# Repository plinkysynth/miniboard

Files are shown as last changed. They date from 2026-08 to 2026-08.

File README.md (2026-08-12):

# miniboard - a super minimal fatar tp9 37 key keybed scanner using an rp2040 mcu by @mmalex.bsky.social

August 2026

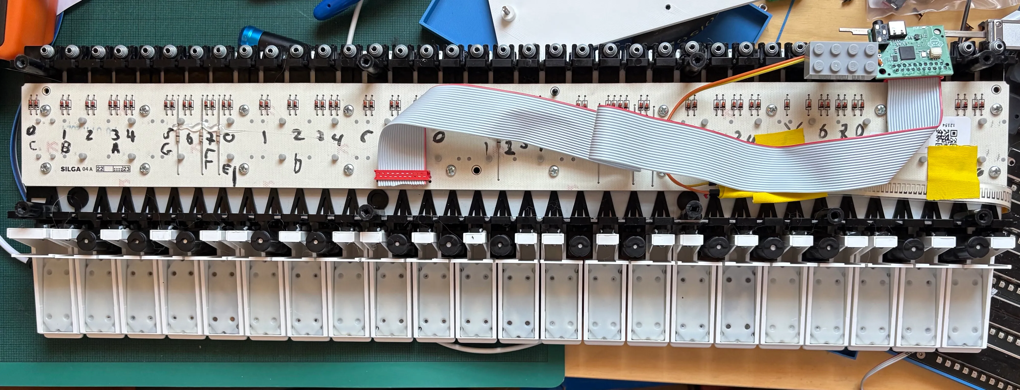
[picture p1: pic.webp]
miniboard


## the keybed wot you need

there's no point looking at this project until you are the proud owner of a fatar 9s keybed. probably the 37 key variant. 

- the keybed - https://www.fatar.com/products/tp9s/
- datasheet - https://www.antonus-synths.com/enlo-1/fatar/DataSheet-TP9S%2BP.pdf

I got mine at great expense a few years ago from
https://enlo-1.com/products/fatar-tp-9s-keyboard
but im not sure if they are meant to sell them to us hobbyists? either way it was expensive for what it is! maybe you can find one cheaper somewhere else. I am not affiliated with them in any way, just documenting my build.

## whence came this mess

forked from my earlier 2024 zacboard project, that included an oled, 2 encoders, and a silly set of i2c slider boards that allowed it to sport more sliders than keys.

im not sure if i ever released that one publically (* i did not), but i was curious about making a super minimal 'fatar keybed and nothing else' the other day, so I stripped everything down, speed-designed a PCB, and re-ordered from JLC. the boards just arrived, they work, I am putting this up on github before thinking too much...

## software

the software just times make/breaks when scanning the keybed, as one must, and uses that to pick a velocity.

it also feeds the aftertouch resistor to ADC0 and uses that to generate aftertouch events.

it sends MIDI messages out on channel 0 on the TRS port and over usb midi. 

the pcb has a 3 pin connector for a raspberry pi debug probe 

https://www.raspberrypi.com/products/debug-probe/

which I highly recommend for all rp2040 hacking projects. it gives you quick way to flash new software without messing with reset buttons, clean debugging in vscode, watch, breakpoints, etc.

i set this project to use rtt segger style printf, which is THE ONE TRUE WAY but is surprisingly underdocumented in the pico sdk. If you have a probe connected you can
see your printf's in vscode via the TERMINAL tab, and its really cheap, and doesnt tie up the USB port or a 
serial port, nor use any GPIOs. lovely!

## hardware

power is over usb-c obviously

i did this in a yolo rush, so its a bit rough.
ordering your own pcbs, its the usual kicad -> jlcpcb -> yay!
I even left the production files checked in, so you could even just upload those straight to JLC. it worked for me, but see the section below on improvements you might want to make before spending money.

all the parts should be readily available via their assembly service.

I accept no responsibility for anything that may come from building this stuff! you're on your own.

## mounting

the open scad file is for a simple plank to screw onto the keybed and mount the circuit board.

a plank of wood or other material would be nicer.

i screwed it into the keybed with 8 wood screws i found in a cupboard :) M3 or M4 I think they were.
the pcb has two m3 holes in it, which I used 2 M3 machine screws and nuts for. the stl/openscad file has holes for these.

## keybed connector

i HATE HATE HATE the minimatch connector that fatar uses, but here we are. you need some 20 way
ribbon cable to clamp it onto, which requires FORCE which often breaks the fragile plastic.
I got the connectors from digikey:

| use | quantity | digikey part | manufacturer | manufacturer part | description |
| --- | ---: | --- | --- | --- | --- |
| for the cable... | 2x | A99456CT-ND | TE CONNECTIVITY AMP (VA) | 9-215083-0 | CONN PLUG 20POS IDC 28AWG TIN |
| for the pcb... | 1x | A99465CT-ND | TE CONNECTIVITY AMP (VA) | 9-215079-0 | CONN RCPT 20POS 0.1 TIN PCB |

and standard 28AWG 20 way ribbon cable.

The keybed also has a little flat flex variable resistor. connect two wires to it
and solder them to the outer two pins of the 4 pin connector on the pcb. voila,
after touch.

## PCB design mistakes chapter:

* i should have connected the last 2 pins to GPIOs. I didn't. as a result you can't scan larger keyboards.
If i was ordering from JLCPCB again, I'd hook up those two not connected pins to GPIOs.

* the TRS jack for midi is too close to the USB-C. it works, but its close.

* obviously it could sprout more connections, encoders, buttons, etc.... but that wasnt the point of 
this minimalist project.  

* it would make sense to expose more of the free GPIOs as testpads or connectors or whatnot.

* the routing is fine, honest.

## license

released into as liberal a license as I can: [CC0](LICENSE.md)...

- alex 'mmalex' evans august 2026

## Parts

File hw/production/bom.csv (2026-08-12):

Designator | Footprint | Quantity | Value | LCSC Part #
C1, C11, C3, C9 | 0402 | 4 | 1uf | C52923
C10, C13, C14, C15, C2, C4, C7, C8 | 0402 | 8 | 100n | C307331
C5, C6 | 0402 | 2 | 18pf | C1549
H1, H2 | MountingHole_3.2mm_M3 | 2 | MountingHole
J1 | VALCON_CSP-USC16-TR | 1 | CSP-USC16-TR | C2765186
J2 | JST_SH_SM03B-SRSS-TB_1x03-1MP_P1.00mm_Horizontal | 1 | Conn_01x03_Pin | C160403
LED1 | LED0603-RD | 1 | KT-0603R | C2286
R1, R11, R12, R2 | 0402 | 4 | 33 | C25105
R10, R13 | 0402 | 2 | 10k | C25744
R3, R6 | 0402 | 2 | 5.1k | C2906948
R4, R5, R7, R8, R9 | 0402 | 5 | 1k | C11702
U1 | SOT-23-3_L2.9-W1.6-P1.90-LS2.8-BR | 1 | XC6206P332MR | C5446
U2 | USON-8_L3.0-W2.0-P0.50-BL-EP | 1 | W25Q16JVUXIQ | C2843335
U3 | QFN-56-1EP_7x7mm_P0.4mm_EP3.2x3.2mm | 1 | RP2040 | C2040
U4 | AUDIO-TH_PJ-3200 | 1 | Black_headphone_jack | C2689690
Y1 | Crystal_SMD_2520-4Pin_2.5x2.0mm | 1 | Crystal_GND24 | C284155

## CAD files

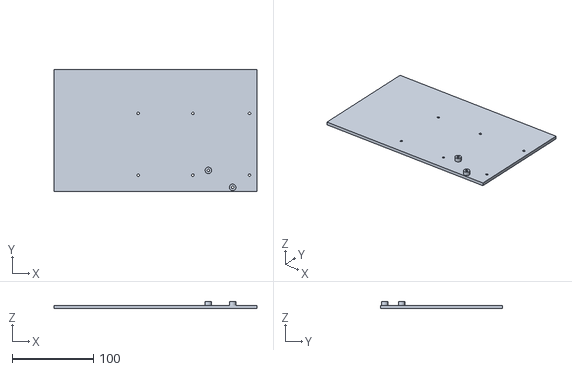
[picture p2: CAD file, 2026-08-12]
hw/standoff_bed.stl
250.0 x 150.0 x 9.10

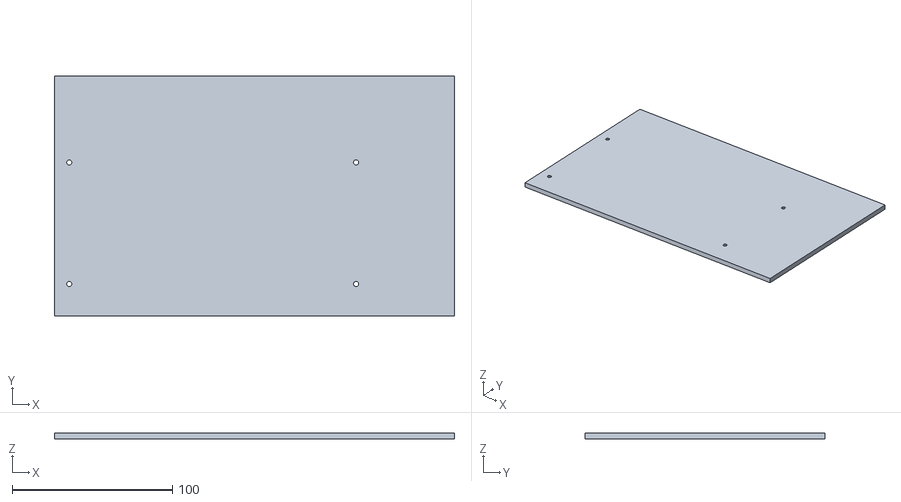
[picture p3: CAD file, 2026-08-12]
hw/standoff_bed2.stl
250.0 x 150.0 x 4.00

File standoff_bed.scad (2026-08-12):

// Flat mounting bed with two rows of M3 standoffs.
// Units are millimetres.

// to make an x-direction cutaway.
// my bambu labs printer can only do 250mm at a time
// so i print it in two parts

// part 1
//clip_min = [250, -1, -1]; // -1, -1, -1
//clip_max = [510, 160, 20]; // 510, 160, 20

// part 2
//clip_min = [-1, -1, -1]; // -1, -1, -1
//clip_max = [250, 160, 20]; // 510, 160, 20

// or just the whole thing in one go
clip_min = [-1, -1, -1]; // -1, -1, -1
clip_max = [510, 160, 20]; // 510, 160, 20


$fn = 64;

bed_x = 500;
bed_y = 150;
bed_thickness = 4;

pillar_diameter = 8;
default_pillar_height = 0;
pcb_pillar_h = default_pillar_height + 5.1;

// M3 socket-head bolt allowances. Adjust for your bolt/printing process.
bolt_hole_diameter = 3.2;
bolt_head_recess_diameter = 6.0;
bolt_head_recess_depth = 2;

epsilon = 0.01;

x_offset = (bed_x - 481.55) / 2;
x_coordinates = [0, 69.72, 137.07, 302.27, 481.55];
y_coordinates = [8, 8+76];

mb_w = 29.845;
mb_h = 20.828;
mb_x = 30;
mb_y = 5;

// Add further entries as [x, y, pillar_height].
// The supplied x coordinates are centred by x_offset here.
risers = [
    for (y = y_coordinates, x = x_coordinates)
        [x + x_offset, y, default_pillar_height]
];

// Positive pillar geometry. Its M3 bore is removed by riser_cutout() below.
module riser(x, y, pillar_height) {
    translate([x, y, bed_thickness])
        cylinder(d = pillar_diameter, h = pillar_height);
}

// M3 clearance bore through the bed and pillar, plus the bolt-head recess
// opening from the bottom of the bed.
module riser_cutout(x, y, pillar_height) {
    translate([x, y, -epsilon])
        cylinder(
            d = bolt_hole_diameter,
            h = bed_thickness + pillar_height + 2 * epsilon
        );

    translate([x, y, -epsilon])
        cylinder(
            d = bolt_head_recess_diameter,
            h = bolt_head_recess_depth + epsilon
        );
}

module riser_cutout2(x, y, pillar_height) {
    translate([x, y, -epsilon])
        cylinder(
            d = bolt_hole_diameter,
            h = bed_thickness + pillar_height + 2 * epsilon
        );

    translate([x, y, -epsilon])

        cylinder(
            h = 4,
               r1=8/2,r2=4/2
        );
}

module complete_bed() {
    difference() {
        union() {
            cube([bed_x, bed_y, bed_thickness]);

            for (r = risers)
                riser(r[0], r[1], r[2]);
            
            riser(mb_x, mb_y, pcb_pillar_h);
            riser(mb_x + mb_w, mb_y + mb_h, pcb_pillar_h);
        }

        for (r = risers)
            riser_cutout2(r[0], r[1], r[2]);
        
        riser_cutout(mb_x, mb_y, pcb_pillar_h);
        riser_cutout(mb_x+mb_w, mb_y+mb_h, pcb_pillar_h);
        
        
    }
}


mirror([1,0,0])
intersection() {
    complete_bed();
    translate(clip_min)
        cube(clip_max - clip_min);
}

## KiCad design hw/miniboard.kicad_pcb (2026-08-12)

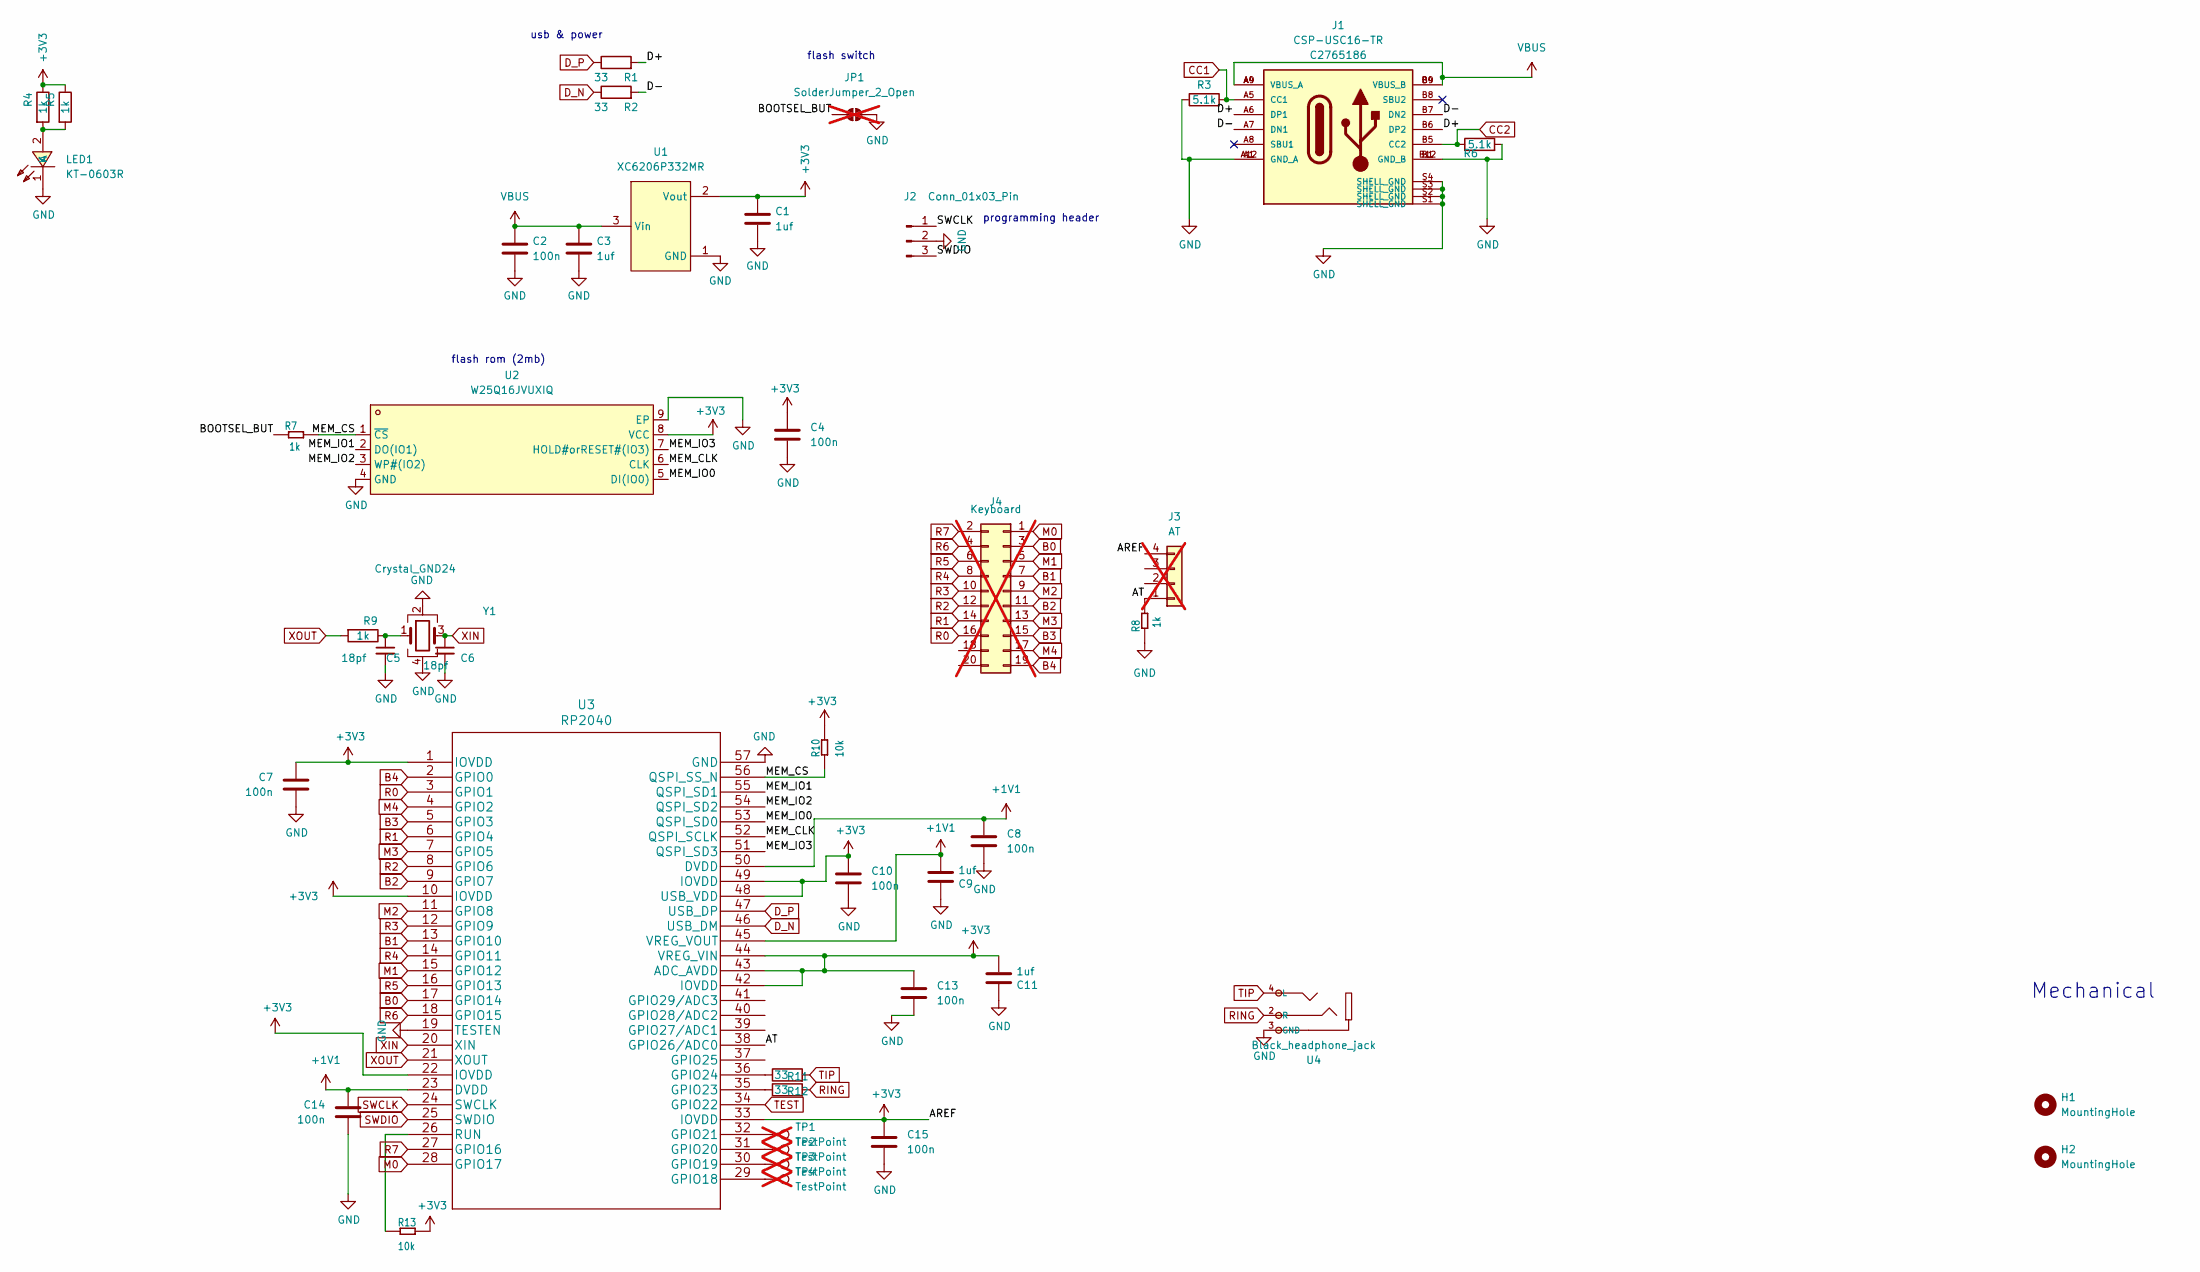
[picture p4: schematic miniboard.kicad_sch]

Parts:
C1, C3, C9, C11: 1uf; C_0402_1005Metric; LCSC C52923
C2, C4, C7, C8, C10, C13, C14, C15: 100n; C_0402_1005Metric; LCSC C307331
C5, C6: 18pf; C_0402_1005Metric; LCSC C1549
H1, H2: MountingHole; MountingHole_3.2mm_M3
J1: CSP-USC16-TR; VALCON_CSP-USC16-TR; PARTREV A0; LCSC C2765186
J2: Conn_01x03_Pin; JST_SH_SM03B-SRSS-TB_1x03-1MP_P1.00mm_Horizontal; LCSC C160403
J3: AT; PinHeader_1x04_P2.54mm_Horizontal; not fitted
J4: Keyboard; TE_9-215079-0; not fitted
JP1: SolderJumper_2_Open; SolderJumper-2_P1.3mm_Open_Pad1.0x1.5mm; not fitted
LED1: KT-0603R; LED0603-RD; LCSC Part C2286
R1, R2, R11, R12: 33; R_0402_1005Metric; LCSC C25105
R3, R6: 5.1k; R_0402_1005Metric; LCSC C2906948
R4, R5, R7, R8, R9: 1k; R_0402_1005Metric; LCSC C11702
R10, R13: 10k; R_0402_1005Metric; LCSC C25744
TP1, TP2, TP3, TP4: TestPoint; TestPoint_Pad_1.5x1.5mm; not fitted
U1: XC6206P332MR; SOT-23-3_L2.9-W1.6-P1.90-LS2.8-BR; LCSC Part C5446
U2: W25Q16JVUXIQ; USON-8_L3.0-W2.0-P0.50-BL-EP; LCSC Part C2843335
U3: RP2040; QFN-56-1EP_7x7mm_P0.4mm_EP3.2x3.2mm; LCSC C2040
U4: Black_headphone_jack; AUDIO-TH_PJ-3200; LCSC C2689690
Y1: Crystal_GND24; Crystal_SMD_2520-4Pin_2.5x2.0mm; LCSC C284155

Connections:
+1V1: C8.1, C9.2, C14.1, U3.23 (DVDD), U3.45 (VREG_VOUT), U3.50 (DVDD)
+3V3: C1.1, C4.1, C7.1, C10.1, C11.2, C13.1, C15.1, J3.4, R4.1, R5.1, R10.2, R13.2, U1.2 (Vout), U2.8 (VCC), U3.1 (IOVDD), U3.10 (IOVDD), U3.22 (IOVDD), U3.33 (IOVDD), U3.42 (IOVDD), U3.43 (ADC_AVDD), U3.44 (VREG_VIN), U3.48 (USB_VDD), U3.49 (IOVDD)
/AT: J3.1, R8.2, U3.38 (GPIO26/ADC0)
/BOOTSEL_BUT: JP1.1 (A), R7.1
/D+: J1.A6 (DP1), J1.B6 (DP2), R1.2
/D-: J1.A7 (DN1), J1.B7 (DN2), R2.2
/MEM_CLK: U2.6 (CLK), U3.52 (QSPI_SCLK)
/MEM_CS: R7.2, R10.1, U2.1 (~CS), U3.56 (QSPI_SS_N)
/MEM_IO0: U2.5 (DI(IO0)), U3.53 (QSPI_SD0)
/MEM_IO1: U2.2 (DO(IO1)), U3.55 (QSPI_SD1)
/MEM_IO2: U2.3 (WP#(IO2)), U3.54 (QSPI_SD2)
/MEM_IO3: U2.7 (HOLD#orRESET#(IO3)), U3.51 (QSPI_SD3)
B0: J4.3, U3.17 (GPIO14)
B1: J4.7, U3.13 (GPIO10)
B2: J4.11, U3.9 (GPIO7)
B3: J4.15, U3.5 (GPIO3)
B4: J4.19, U3.2 (GPIO0)
CC1: J1.A5 (CC1), R3.2
CC2: J1.B5 (CC2), R6.1
D_N: R2.1, U3.46 (USB_DM)
D_P: R1.1, U3.47 (USB_DP)
GND: C1.2, C2.2, C3.2, C4.2, C5.2, C6.2, C7.2, C8.2, C9.1, C10.2, C11.1, C13.2, C14.2, C15.2, J1.A1 (GND_A), J1.A12 (GND_A), J1.B1 (GND_B), J1.B12 (GND_B), J1.S1 (SHELL_GND), J1.S2 (SHELL_GND), J1.S3 (SHELL_GND), J1.S4 (SHELL_GND), J2.2, JP1.2 (B), LED1.1 (K), R3.1, R6.2, R8.1, U1.1 (GND), U2.4 (GND), U2.9 (EP), U3.19 (TESTEN), U3.57 (GND), U4.3 (GND), Y1.2, Y1.4
M0: J4.1, U3.28 (GPIO17)
M1: J4.5, U3.15 (GPIO12)
M2: J4.9, U3.11 (GPIO8)
M3: J4.13, U3.7 (GPIO5)
M4: J4.17, U3.4 (GPIO2)
unnamed: C5.1, R9.1, Y1.1
unnamed: LED1.2 (A), R4.2, R5.2
unnamed: TP4.1, U3.29 (GPIO18)
unnamed: TP3.1, U3.30 (GPIO19)
unnamed: TP2.1, U3.31 (GPIO20)
unnamed: TP1.1, U3.32 (GPIO21)
unnamed: R12.1, U3.35 (GPIO23)
unnamed: R11.1, U3.36 (GPIO24)
unnamed: R13.1, U3.26 (RUN)
R0: J4.16, U3.3 (GPIO1)
R1: J4.14, U3.6 (GPIO4)
R2: J4.12, U3.8 (GPIO6)
R3: J4.10, U3.12 (GPIO9)
R4: J4.8, U3.14 (GPIO11)
R5: J4.6, U3.16 (GPIO13)
R6: J4.4, U3.18 (GPIO15)
R7: J4.2, U3.27 (GPIO16)
RING: R12.2, U4.2 (R)
SWCLK: J2.1, U3.24 (SWCLK)
SWDIO: J2.3, U3.25 (SWDIO)
TEST: U3.34 (GPIO22)
TIP: R11.2, U4.4 (L)
VBUS: C2.1, C3.1, J1.A4 (VBUS_A), J1.A9 (VBUS_A), J1.B4 (VBUS_B), J1.B9 (VBUS_B), U1.3 (Vin)
XIN: C6.1, U3.20 (XIN), Y1.3
XOUT: R9.2, U3.21 (XOUT)

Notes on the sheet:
programming header
Mechanical
usb & power
flash switch
flash rom (2mb)

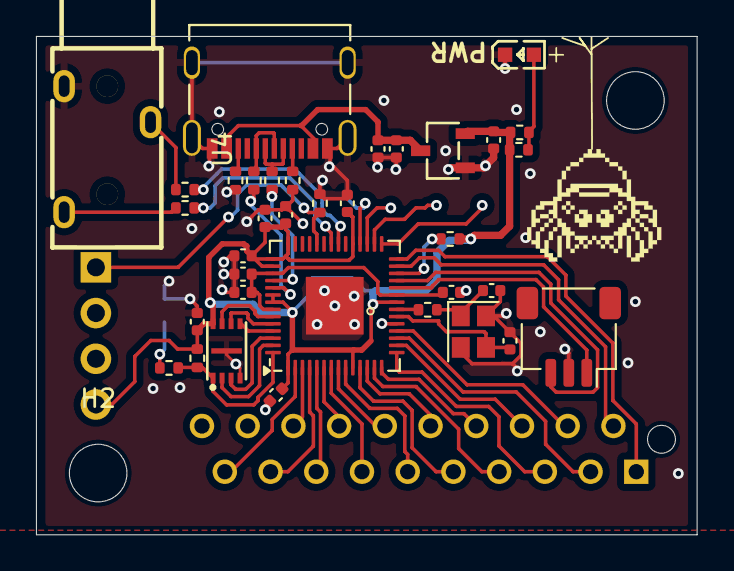
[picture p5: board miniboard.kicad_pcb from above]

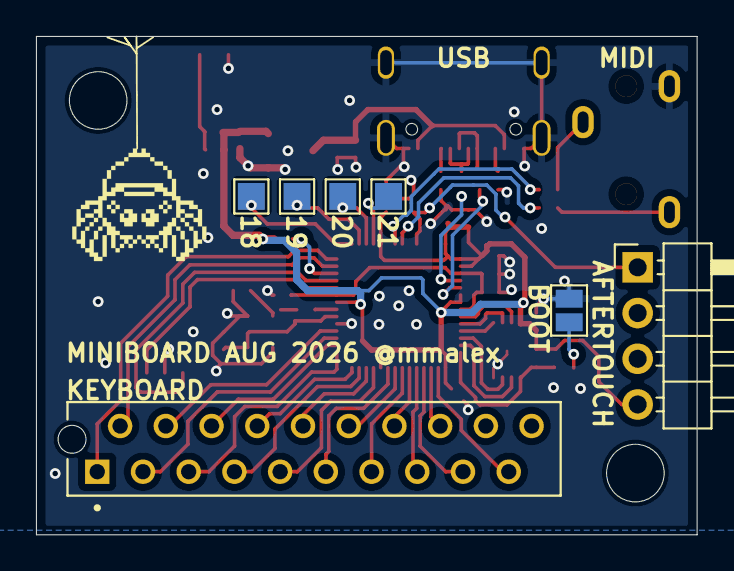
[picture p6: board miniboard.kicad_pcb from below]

Board: 2 copper layers, 36.7 x 27.7 mm, 44 parts (7 on the bottom side), 51 nets.

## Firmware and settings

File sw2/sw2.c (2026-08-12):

#include <stdbool.h>
#include <stdint.h>
#include <stdio.h>

#include "hardware/adc.h"
#include "hardware/pio.h"
#include "pico/stdio_rtt.h"
#include "pico/stdlib.h"
#include "uart_tx.pio.h"
#include "usb.c"

// Set to 0 to build without channel aftertouch from ADC0 / GPIO26.
#ifndef ENABLE_AFTERTOUCH
#define ENABLE_AFTERTOUCH 1
#endif

// Set to 1 to swap which TRS contact carries MIDI. Type A is the default.
#ifndef MIDI_TYPE_B
#define MIDI_TYPE_B 0
#endif

#define MIDI_CHANNEL 0
#define BASE_MIDI_NOTE 48
#define VELOCITY_SENSITIVITY 64

#define MIDI_TX_TIP 23
#define MIDI_TX_RING 24
#define AFTERTOUCH_PIN 26
#define AFTERTOUCH_ADC_CHANNEL 0

#define MIDI_TX_PIO pio0
#define MIDI_TX_SM 0
#define MIDI_BAUD 31250

// Fatar keybed pins, in GPIO order:
// B4, R0, M4, B3, R1, M3, R2, B2,
// M2, R3, B1, R4, M1, R5, B0, R6, R7, M0.
#define B4 0
#define R0 1
#define M4 2
#define B3 3
#define R1 4
#define M3 5
#define R2 6
#define B2 7
#define M2 8
#define R3 9
#define B1 10
#define R4 11
#define M1 12
#define R5 13
#define B0 14
#define R6 15
#define R7 16
#define M0 17

#define KEY_ROWS 8
#define KEY_COLUMNS 5
#define KEY_COUNT (KEY_ROWS * KEY_COLUMNS)

// The schematic's row labels run in the opposite direction to the key order.
static const uint8_t row_pins[KEY_ROWS] = {R7, R6, R5, R4, R3, R2, R1, R0};
static const uint8_t break_pins[KEY_COLUMNS] = {B0, B1, B2, B3, B4};
static const uint8_t make_pins[KEY_COLUMNS] = {M0, M1, M2, M3, M4};

#define ROW_PIN_MASK                                                                                                  \
    ((1u << R0) | (1u << R1) | (1u << R2) | (1u << R3) | (1u << R4) | (1u << R5) | (1u << R6) | (1u << R7))

static uint32_t break_time[KEY_COUNT];
static uint8_t note_velocity[KEY_COUNT];

static int clamp_int(int value, int minimum, int maximum) {
    if (value < minimum) return minimum;
    if (value > maximum) return maximum;
    return value;
}

static void gpio_init_output(uint pin, bool value) {
    gpio_init(pin);
    gpio_put(pin, value);
    gpio_set_dir(pin, GPIO_OUT);
}

static void gpio_init_input_pulldown(uint pin) {
    gpio_init(pin);
    gpio_set_dir(pin, GPIO_IN);
    gpio_set_pulls(pin, false, true);
}

static void keyboard_init(void) {
    for (int row = 0; row < KEY_ROWS; ++row) gpio_init_output(row_pins[row], false);
    for (int column = 0; column < KEY_COLUMNS; ++column) {
        gpio_init_input_pulldown(break_pins[column]);
        gpio_init_input_pulldown(make_pins[column]);
    }
}

static void midi_out_init(bool type_b) {
    // A TRS MIDI output drives one contact with serial data and holds the other high.
    gpio_init_output(MIDI_TX_TIP, true);
    gpio_init_output(MIDI_TX_RING, true);

    uint offset = pio_add_program(MIDI_TX_PIO, &uart_tx_program);
    uint tx_pin = type_b ? MIDI_TX_TIP : MIDI_TX_RING;
    uart_tx_program_init(MIDI_TX_PIO, MIDI_TX_SM, offset, tx_pin, MIDI_BAUD);
}

static int midi_message_length(uint8_t status) {
    uint8_t message_type = status & 0xf0u;
    return (message_type == 0xc0u || message_type == 0xd0u) ? 2 : 3;
}

static void midi_send(uint8_t status, uint8_t data1, uint8_t data2) {
    int length = midi_message_length(status);
    pio_sm_put_blocking(MIDI_TX_PIO, MIDI_TX_SM, status);
    pio_sm_put_blocking(MIDI_TX_PIO, MIDI_TX_SM, data1);
    if (length == 3) pio_sm_put_blocking(MIDI_TX_PIO, MIDI_TX_SM, data2);
    usb_midi_write(status, data1, data2, length);

    if (length == 2) printf("MIDI: %02x %02x\n", status, data1);
    else printf("MIDI: %02x %02x %02x\n", status, data1, data2);
}

#if ENABLE_AFTERTOUCH
static void aftertouch_init(void) {
    adc_init();
    gpio_set_pulls(AFTERTOUCH_PIN, false, false);
    adc_gpio_init(AFTERTOUCH_PIN);
    adc_select_input(AFTERTOUCH_ADC_CHANNEL);
    hw_set_bits(&adc_hw->cs, ADC_CS_START_ONCE_BITS);
}

// Input is a 12-bit ADC reading scaled by 16, which preserves precision when
// it comes from the 256-sample accumulator below.
static uint8_t aftertouch_from_adc_16x(int adc_16x) {
    if (adc_16x <= 0) return 0;

    // The Fatar strip is approximately 2.2k at the start of its useful range
    // to 200 ohms fully pressed, through the board's 1k divider to ground.
    const int start_resistance = 2200;
    const int end_resistance = 200;
    const int divider_resistance = 1000;
    const int adc_full_scale_16x = 4095 * 16;
    int resistance = divider_resistance * adc_full_scale_16x / adc_16x - divider_resistance;
    int aftertouch_q10 = (start_resistance - resistance) * 1024 / (start_resistance - end_resistance);
    aftertouch_q10 = clamp_int(aftertouch_q10, 0, 1023);
    return (uint8_t)((aftertouch_q10 * aftertouch_q10) >> 13);
}

static void aftertouch_update(void) {
    if (!(adc_hw->cs & ADC_CS_READY_BITS)) return;

    static int accumulator;
    static int sample_count;
    static uint8_t last_value;
    static uint32_t last_send_time;
    static uint32_t last_raw_print_time;
    enum { OVERSAMPLE_COUNT = 256 };

    uint16_t raw_adc = (uint16_t)adc_hw->result;
    accumulator += raw_adc;
    ++sample_count;
    hw_set_bits(&adc_hw->cs, ADC_CS_START_ONCE_BITS);

    uint32_t now = time_us_32();
    if ((uint32_t)(now - last_raw_print_time) >= 100000u) {
        uint8_t raw_mapped = aftertouch_from_adc_16x((int)raw_adc * 16);
        printf("aftertouch: raw ADC=%u mapped MIDI=%u\n", raw_adc, raw_mapped);
        last_raw_print_time = now;
    }

    if (sample_count != OVERSAMPLE_COUNT) return;

    int adc_16x = accumulator / (OVERSAMPLE_COUNT / 16);
    uint8_t aftertouch = aftertouch_from_adc_16x(adc_16x);

    accumulator = 0;
    sample_count = 0;

    if ((uint32_t)(now - last_send_time) > 10000u && aftertouch != last_value) {
        midi_send(0xd0u | MIDI_CHANNEL, aftertouch, 0);
        last_value = aftertouch;
        last_send_time = now;
    }
}
#endif

static void keyboard_scan(void) {
    static uint8_t scan_row = KEY_ROWS - 1;
    static uint32_t scan_start_time;
    static uint32_t full_scan_time;

    scan_row = (scan_row + 1) & (KEY_ROWS - 1);

    // Only touch the matrix row latches: gpio_put_all() would pull the idle
    // MIDI contact low because it is also an SIO output.
    gpio_put_masked(ROW_PIN_MASK, 1u << row_pins[scan_row]);
    sleep_us(20);

    uint32_t gpios = gpio_get_all();
    uint32_t now = time_us_32();
    if (now == 0) now = 1; // Zero is the "not yet pressed" sentinel.

    if (scan_row == 0) {
        if (scan_start_time != 0) full_scan_time = now - scan_start_time;
        scan_start_time = now;
    }

    for (int column = 0; column < KEY_COLUMNS; ++column) {
        bool break_contact = (gpios >> break_pins[column]) & 1u;
        bool make_contact = (gpios >> make_pins[column]) & 1u;
        int key = scan_row + column * KEY_ROWS;

        if (break_contact) {
            if (break_time[key] == 0) break_time[key] = now;

            if (make_contact && note_velocity[key] == 0) {
                uint32_t travel_time = now - break_time[key];
                int hard_time_us = VELOCITY_SENSITIVITY * 100;
                const int soften_us = 1000;
                int semitone = key % 12;
                bool black_key = semitone == 1 || semitone == 3 || semitone == 6 || semitone == 8 || semitone == 10;
                if (black_key) hard_time_us = hard_time_us * 3 / 4;

                int velocity = (hard_time_us + soften_us) * 127 / ((int)travel_time + soften_us);
                velocity = clamp_int(velocity, 1, 127);
                note_velocity[key] = (uint8_t)velocity;

                uint8_t note = (uint8_t)(BASE_MIDI_NOTE + key);
                printf("note on: key=%d note=%u travel=%uus velocity=%d scan=%uus\n", key, note,
                       (unsigned)travel_time, velocity, (unsigned)full_scan_time);
                midi_send(0x90u | MIDI_CHANNEL, note, (uint8_t)velocity);
            }
        } else {
            if (note_velocity[key] != 0) {
                uint8_t note = (uint8_t)(BASE_MIDI_NOTE + key);
                printf("note off: key=%d note=%u\n", key, note);
                midi_send(0x80u | MIDI_CHANNEL, note, 0);
                note_velocity[key] = 0;
            }
            break_time[key] = 0;
        }
    }
}

int main(void) {
    stdio_rtt_init();
    keyboard_init();
    midi_out_init(MIDI_TYPE_B != 0);
    usb_midi_init();
#if ENABLE_AFTERTOUCH
    aftertouch_init();
#endif

    printf("sw2: Fatar scanner, RTT debug, TRS MIDI type %c on GPIO%d/%d\n",
           MIDI_TYPE_B ? 'B' : 'A', MIDI_TX_TIP, MIDI_TX_RING);
    printf("aftertouch: %s\n", ENABLE_AFTERTOUCH ? "enabled" : "disabled");

    while (true) {
        usb_midi_task();
#if ENABLE_AFTERTOUCH
        aftertouch_update();
#endif
        keyboard_scan();
    }
}

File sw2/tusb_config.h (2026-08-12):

#ifndef TUSB_CONFIG_H
#define TUSB_CONFIG_H

#define BOARD_TUD_RHPORT 0
#define BOARD_TUD_MAX_SPEED OPT_MODE_DEFAULT_SPEED

#ifndef CFG_TUSB_OS
#define CFG_TUSB_OS OPT_OS_NONE
#endif

#define CFG_TUSB_RHPORT0_MODE OPT_MODE_DEVICE
#define CFG_TUD_ENABLED 1
#define CFG_TUD_MAX_SPEED BOARD_TUD_MAX_SPEED
#define CFG_TUSB_MEM_ALIGN __attribute__((aligned(4)))
#define CFG_TUD_ENDPOINT0_SIZE 64

// MIDI only: no CDC serial, mass storage, HID, or vendor interface.
#define CFG_TUD_CDC 0
#define CFG_TUD_MSC 0
#define CFG_TUD_HID 0
#define CFG_TUD_MIDI 1
#define CFG_TUD_VENDOR 0

#define CFG_TUD_MIDI_RX_BUFSIZE 64
#define CFG_TUD_MIDI_TX_BUFSIZE 256

#endif

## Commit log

2026-08-12 fix build paths; change pid to not clash with plinky 12 ;)
2026-08-12 move the holes back a bit
    [standoff_bed.scad]
